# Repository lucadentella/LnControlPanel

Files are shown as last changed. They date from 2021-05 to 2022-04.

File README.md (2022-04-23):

# LnControlPanel
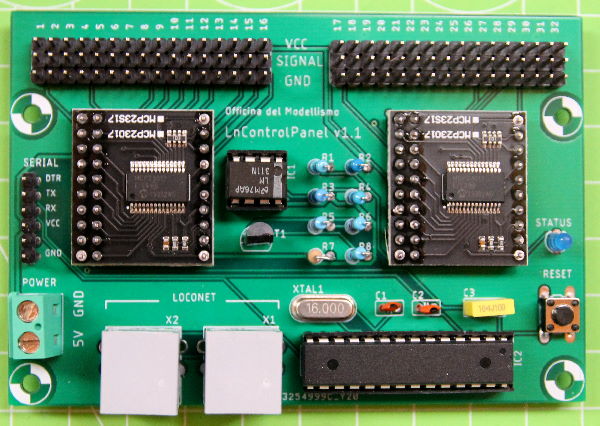
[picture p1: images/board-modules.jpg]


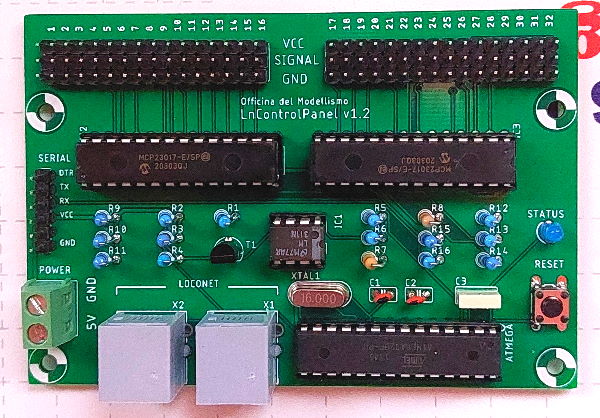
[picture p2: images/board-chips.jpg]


## Description

LnControlPanel is an opensource board to create Loconet control panels.



## What's new :tada:

- 23/04/2022, new board version, with MCP23017 chips instead of CJMCU modules
- 05/03/2022, new firmware (2.0) with support for new Adafruit libraries

## Features :trophy:

 - **32** independent channels:
   - each channel can be configured as **input** (to *control*) or as **output** (to *monitor)*
   - each channel can control/monitor a **turnout** or a **sensor**
   - each channel can have its own **address**
 - Two Loconet connectors for **cascade** connection
 - Based on **Arduino** framework and opensource libraries
 - Configurable using a simple **menu** via **serial** connection

## Tutorials :video_camera:
 - [LnControlPanel on Youtube (ENG)](https://youtu.be/r6l4IHOCdZg)
 - [LnControlPanel su Youtube (ITA)](https://youtu.be/eZ9PHgq4dks)

## Resources :open_file_folder:
 - [Eagle files - board with CJMCU modules](https://github.com/lucadentella/LnControlPanel/tree/main/Eagle/Modules) (schematic / PCB)
 - [Eagle files - board with MCP23017 chips](https://github.com/lucadentella/LnControlPanel/tree/main/Eagle/Chips) (schematic / PCB) 
 - [Arduino firmware](https://github.com/lucadentella/LnControlPanel/tree/main/Arduino)

## Documentation :notebook:
 - [Schematic - board with CJMCU modules](https://github.com/lucadentella/LnControlPanel/tree/main/Documentation/Schematics-modules.pdf) (PDF)
 - [Schematic - board with MCP23017 chips](https://github.com/lucadentella/LnControlPanel/tree/main/Documentation/Schematics-chips.pdf) (PDF)
 - [Part list](https://github.com/lucadentella/LnControlPanel/tree/main/Documentation/PARTLIST.md)
 - [How to configure the channels](https://github.com/lucadentella/LnControlPanel/tree/main/Documentation/CONFIGURATION.md)
 - [How to connect buttons/LEDs](https://github.com/lucadentella/LnControlPanel/tree/main/Documentation/CONNECTIONS.md) 

## Requirements :heavy_check_mark:
 - [mrrwa Loconet Library](https://github.com/mrrwa/LocoNet)
 - [Adafruit MCP23017 Library](https://github.com/adafruit/Adafruit-MCP23017-Arduino-Library)

*The libraries above can be installed via the* [Library Manager](https://www.arduino.cc/en/guide/libraries)

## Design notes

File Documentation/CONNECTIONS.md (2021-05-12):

# Connections :zap:

LnControlPanel has **32 independent** channels. Each channel can be connected to:
 - a **BUTTON** (if the channel is in INPUT mode)
 - one or two **LEDs** (if the channel is in OUTPUT mode)

See [Configuration](https://github.com/lucadentella/LnControlPanel/blob/main/Documentation/CONFIGURATION.md) to learn how to configure channel properties. 
 
 ## INPUT - Button
In INPUT mode, a channel can **control** the status of a sensor or the position of a turnout.

Connect a button between **SIGNAL** and **GND**:

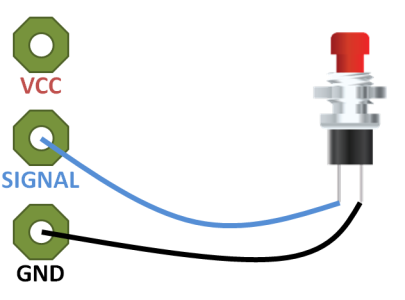
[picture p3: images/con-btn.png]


When the button is pressed, the status of the sensor or the position of the turnout is **switched**.

If the channel is configured as **MSENSOR** (*Momentary Sensor*), the sensor is set **ACTIVE** when the button is pressed and **INACTIVE** when released.

## OUTPUT - LEDs
In OUTPUT mode, a channel can **monitor** the status of a sensor or the position of a turnout.

If you connect the LED between **VCC** and **SIGNAL**, it will be ON if the sensor is **INACTIVE** or the turnout is **STRAIGHT**:
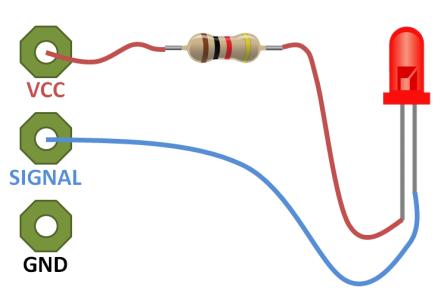
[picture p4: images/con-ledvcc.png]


If you connect the LED between **SIGNAL** and **GND**, it will be ON if the sensor is **ACTIVE** or the turnout is **DIVERGING**:
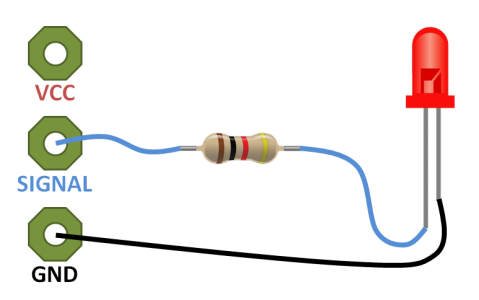
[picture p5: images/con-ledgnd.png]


If you connect **two LEDs** as follows, they will be **ON** based on the turnout position:
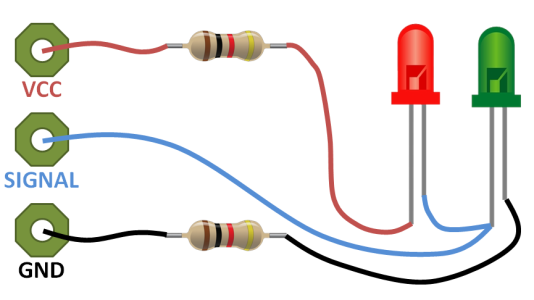
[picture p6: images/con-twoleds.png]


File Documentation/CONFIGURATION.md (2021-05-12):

# Configuration :gear:

LnControlPanel has **32 independent** channels; each channel can be configured in:

 - **OUTPUT** mode (the channel *monitors* an element of the layout)
 - **INPUT** mode (the channel *controls* an element of the layout)

The layout elements associated to each channel can be:
 - **Turnouts**
 - **Sensors**
 - **Momentary** Sensors (*only in* INPUT *mode*)

Each layout element is identified by its **address**.

To summarize, each channel has the following parameters:
|Direction|Device|Address|
|--|--|--|
|Input/Output|Turnout/Sensor/MSensor|*element address*

See [Connections](https://github.com/lucadentella/LnControlPanel/blob/main/Documentation/CONNECTIONS.md) to learn how to connect buttons/LEDs to the channels. 

## Serial console :electric_plug:
It is possible to configure LnControlPanel using a **serial terminal** (for example *Arduino Serial Monitor*).

Using an USB->Serial adapter, connect your computer to the board. 
Make sure that TX and RX pins are **reversed**.

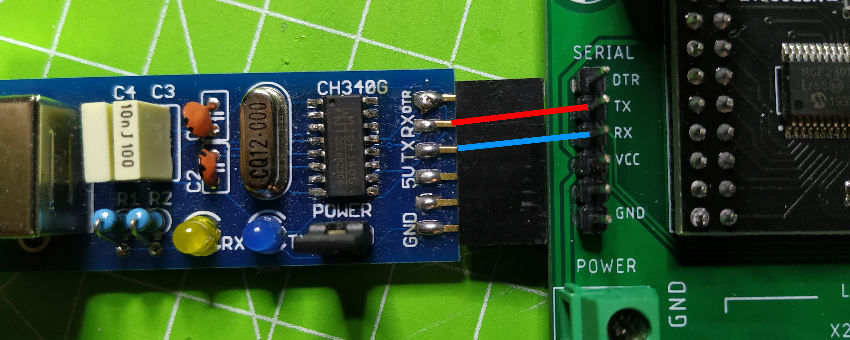
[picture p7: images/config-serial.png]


Open the terminal (**115200** baud, **8N1**, **NL** as line terminator).

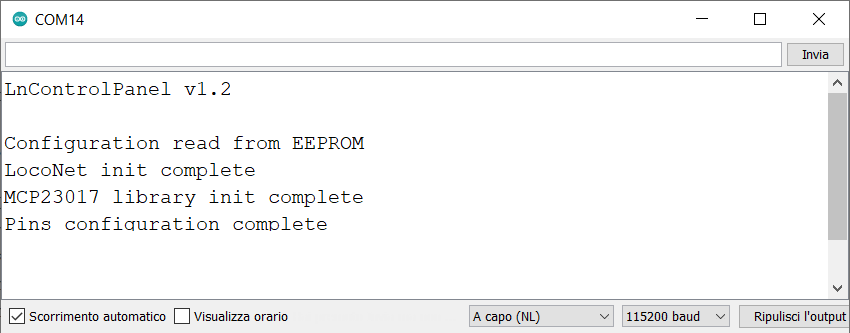
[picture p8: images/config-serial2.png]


The available commands (case sensitive!) are:

 - **INPUT** *ioPin*: set the ioPin as INPUT
 - **OUTPUT** *ioPin*: set the ioPin as OUTPUT
 - **TURNOUT** *ioPin*: set the ioPin as a TURNOUT
 - **SENSOR** *ioPin*: set the ioPin as a SENSOR
 - **MSENSOR** *ioPin*: set the ioPin as a MOMENTARY SENSOR
 - **ADDRESS** *ioPin* *address*: set the address for the ioPin
 - **STATUS**: print the current status
 - **RESET**: reset the configuration to factory
 - **HELP**: print the usage

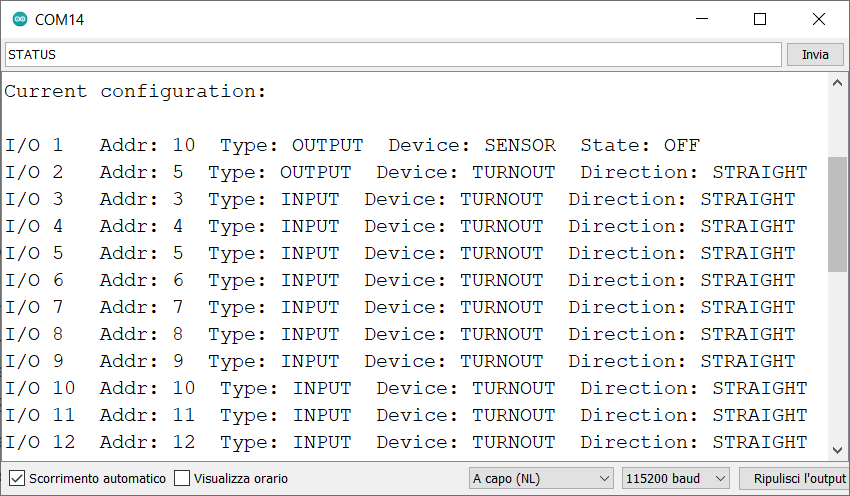
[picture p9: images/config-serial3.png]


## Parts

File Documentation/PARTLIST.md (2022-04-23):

# Part list :gift:

## CJMCU modules version
| ID | Description | 
|--|--|
| R1 | 1Kohm 1/4W resistor |
| R2,3 | 10Kohm 1/4W resistor |
| R4 | 22Kohm 1/4W resistor |
| R5 | 220Kohm 1/4W resistor |
| R6 | 47Kohm 1/4W resistor |
| R7 | 150Kohm 1/4W resistor |
| R8 | 4.7Kohm 1/4W resistor |
| C1,C2 | 22pF ceramic capacitor |
| C3 | 100nF ceramic capacitor |
| XTAL1 | 16MHz crystal oscillator |
| T1 | BC337 NPN transistor |
| LED1 | 3mm LED |
| IC1 | LM311N |
| U1 | ATmega328p |
| M1,M2 | CJMCU-2317 module |
| RESET_SW | Tactile pushbutton |
| X1,X2 | RJ11 PCB connector |
| X3 | 2P terminal block |
| JP1,JP2 | 3x16 pin header |
| JP3 | 1x6 pin header |

## MCP23017 chips version
| ID | Description | 
|--|--|
| R1 | 1Kohm 1/4W resistor |
| R2,3,9,10,11,12,13,14,15,16 | 10Kohm 1/4W resistor |
| R4 | 22Kohm 1/4W resistor |
| R5 | 220Kohm 1/4W resistor |
| R6 | 47Kohm 1/4W resistor |
| R7 | 150Kohm 1/4W resistor |
| R8 | 4.7Kohm 1/4W resistor |
| C1,C2 | 22pF ceramic capacitor |
| C3 | 100nF ceramic capacitor |
| XTAL1 | 16MHz crystal oscillator |
| T1 | BC337 NPN transistor |
| LED1 | 3mm LED |
| IC1 | LM311N |
| U1 | ATmega328p |
| IC2,IC3 | MCP23017 PDIP-28 |
| RESET_SW | Tactile pushbutton |
| X1,X2 | RJ11 PCB connector |
| X3 | 2P terminal block |
| JP1,JP2 | 3x16 pin header |
| JP3 | 1x6 pin header |

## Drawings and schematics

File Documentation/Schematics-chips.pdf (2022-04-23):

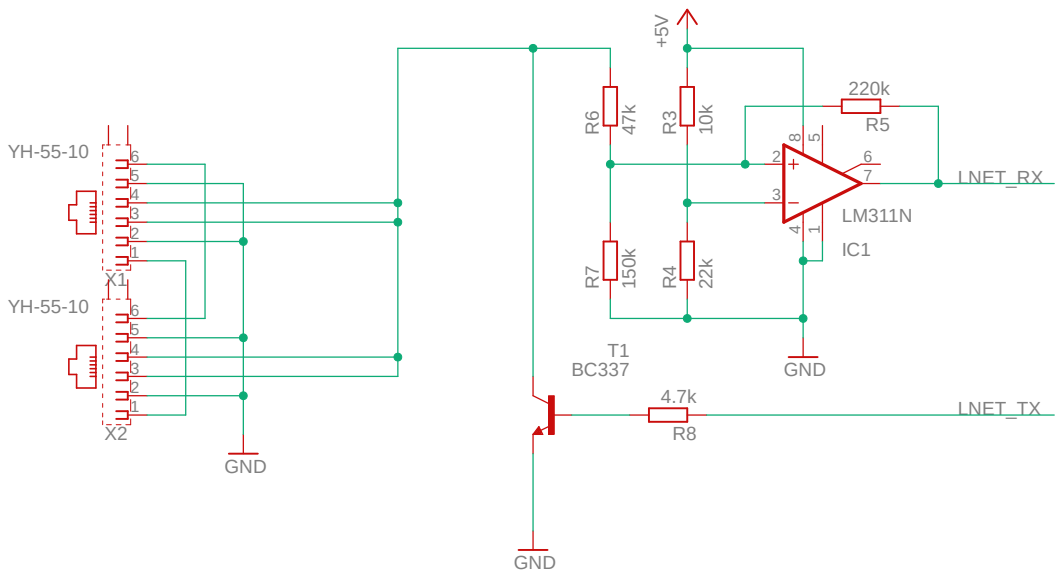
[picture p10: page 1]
LM311N ¹⁰k +5V; GND ²²k; GND; R8 ¹²³⁴⁵⁶ X1 123456 X2; LNET_RX; LNET_TX

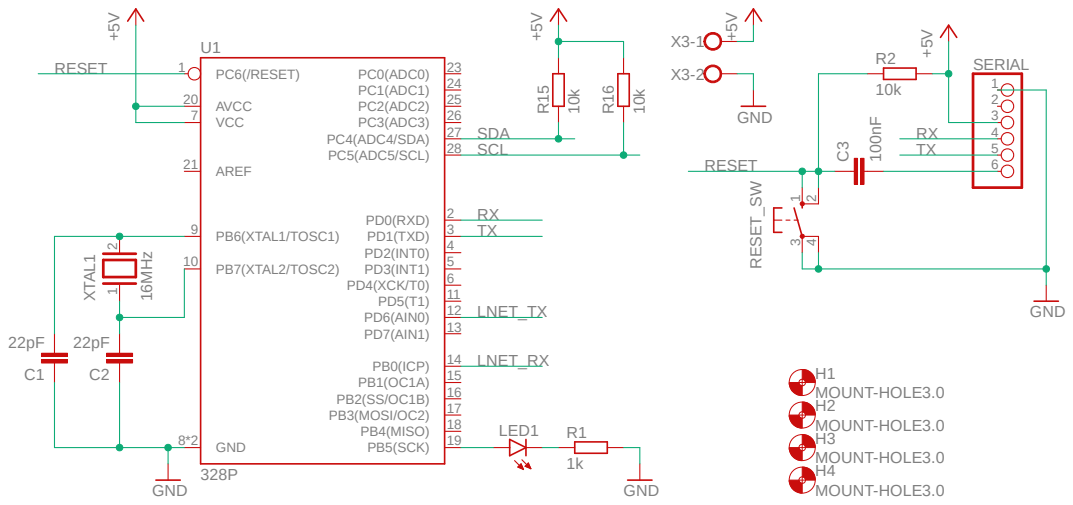
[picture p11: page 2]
GND ⁺⁵V; 16MHz; GND ¹⁰⁰nF; GND; MOUNT-HOLE3.0; MOUNT-HOLE3.0 ⁺⁵V; PB5(SCK); PB7(XTAL2/TOSC2) 10; PB6(XTAL1/TOSC1) 9; GND 8*2; VCC 7; AREF 21; AVCC 20; PB4(MISO); 18 PB3(MOSI/OC2); 15 PB0(ICP); PD7(AIN1); 13 PD6(AIN0); 11 PD4(XCK/T0); PD3(INT1); PD2(INT0); PD1(TXD); PD0(RXD); PC5(ADC5/SCL); 28 PC4(ADC4/SDA); 27 PC3(ADC3); 26 PC2(ADC2); 25 PC1(ADC1); 24 PC0(ADC0); 23 PC6(/RESET) 1 U1; 2 1XTAL1; R2 3 12 4 RESET_SW; 6 SERIAL C³; LED1; X3-2 R¹⁵; R¹⁶; RESET; LNET_TX; LNET_RX; SCL; SDA

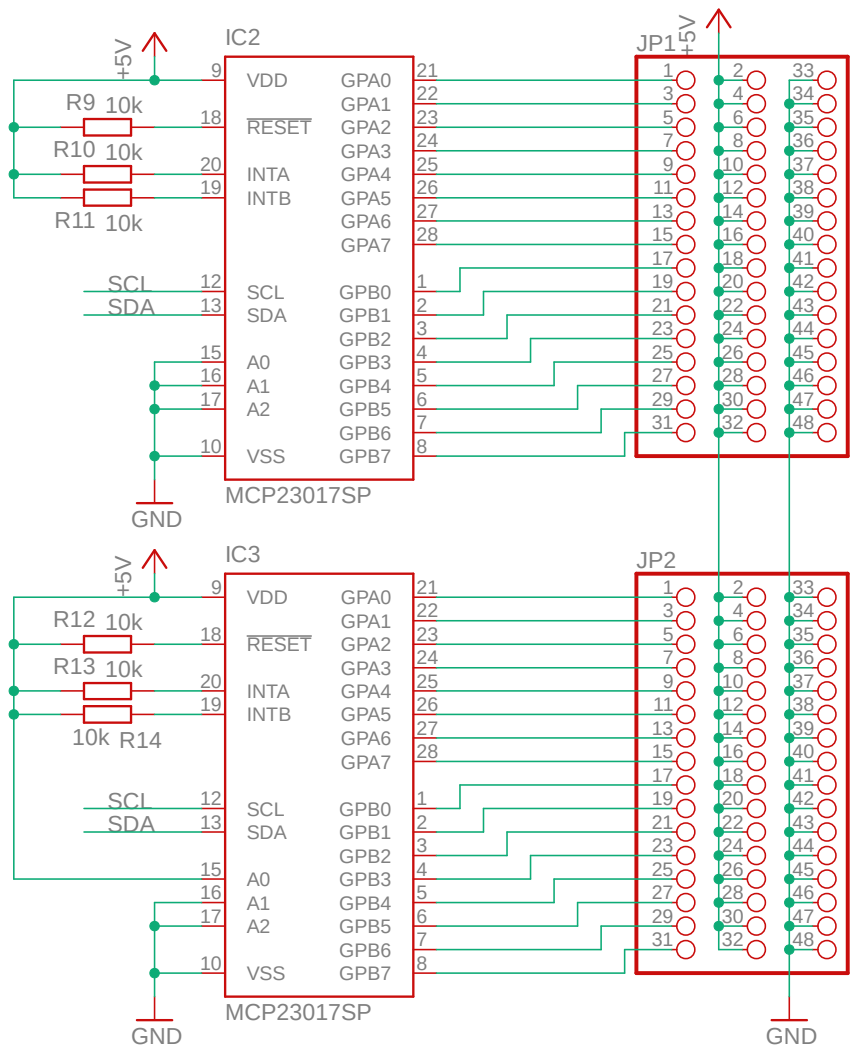
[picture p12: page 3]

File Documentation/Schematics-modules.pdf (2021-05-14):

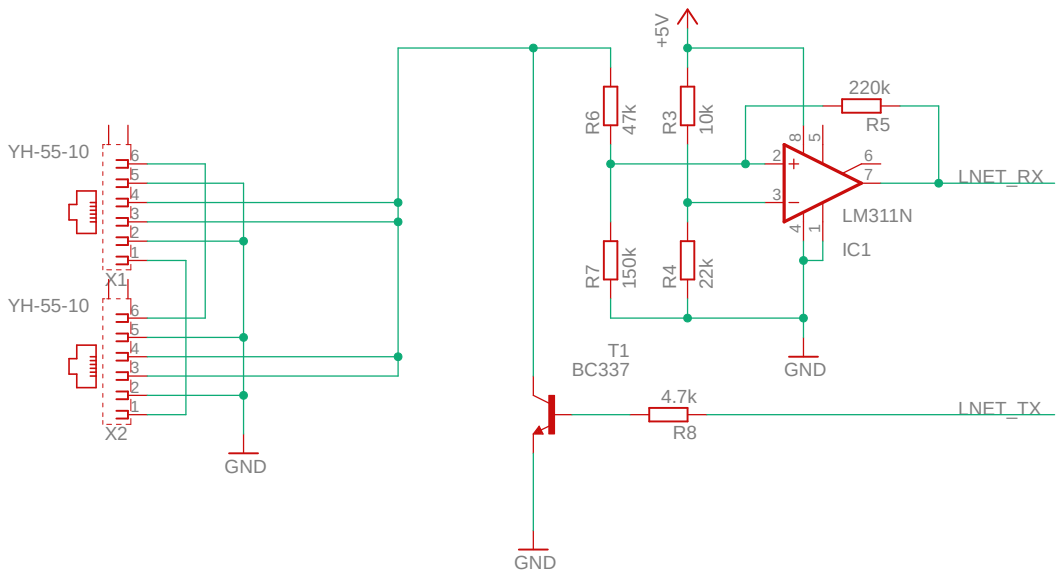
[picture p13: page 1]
LM311N ¹⁰k +5V; GND ²²k; GND; R8 ¹²³⁴⁵⁶ X1 123456 X2; LNET_RX; LNET_TX

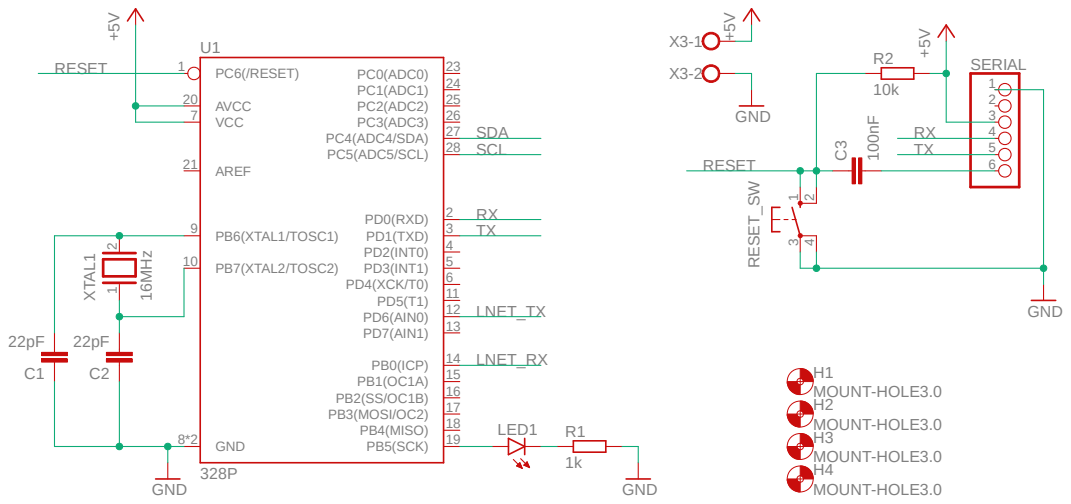
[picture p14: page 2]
GND ⁺⁵V; 16MHz; GND ¹⁰⁰nF; GND; MOUNT-HOLE3.0; MOUNT-HOLE3.0 ⁺⁵V; PB5(SCK); PB7(XTAL2/TOSC2) 10; PB6(XTAL1/TOSC1) 9; GND 8*2; VCC 7; AREF 21; AVCC 20; PB4(MISO); 18 PB3(MOSI/OC2); 15 PB0(ICP); PD7(AIN1); 13 PD6(AIN0); 11 PD4(XCK/T0); PD3(INT1); PD2(INT0); PD1(TXD); PD0(RXD); PC5(ADC5/SCL); 28 PC4(ADC4/SDA); 27 PC3(ADC3); 26 PC2(ADC2); 25 PC1(ADC1); 24 PC0(ADC0); 23 PC6(/RESET) 1 U1; 2 1XTAL1; R2 3 12 4 RESET_SW; 6 SERIAL C³; LED1; RESET; LNET_TX; LNET_RX; SCL; SDA

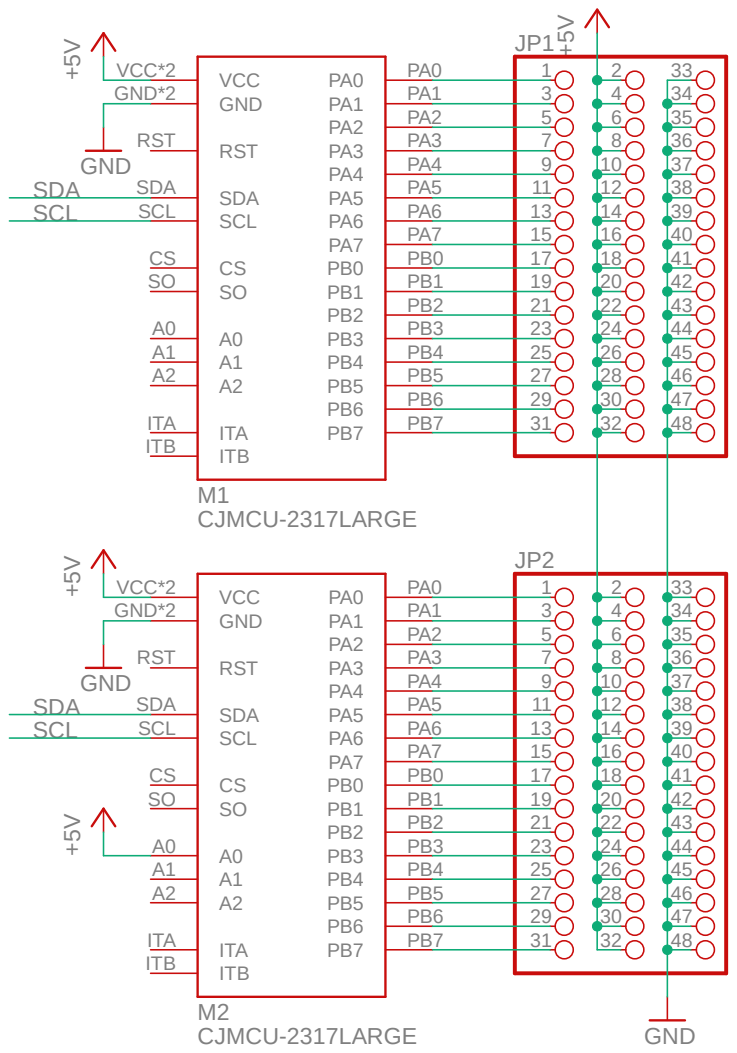
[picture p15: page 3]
CJMCU-2317LARGE; CJMCU-2317LARGE ⁺⁵V +5V; GND; GND +5V; VCC VCC*2 GND GND*2; RST RST; SDA SDA SCL SCL; PB7 ITA ITA; ITB ITB M1; ITB ITB M2; SDA; SCL

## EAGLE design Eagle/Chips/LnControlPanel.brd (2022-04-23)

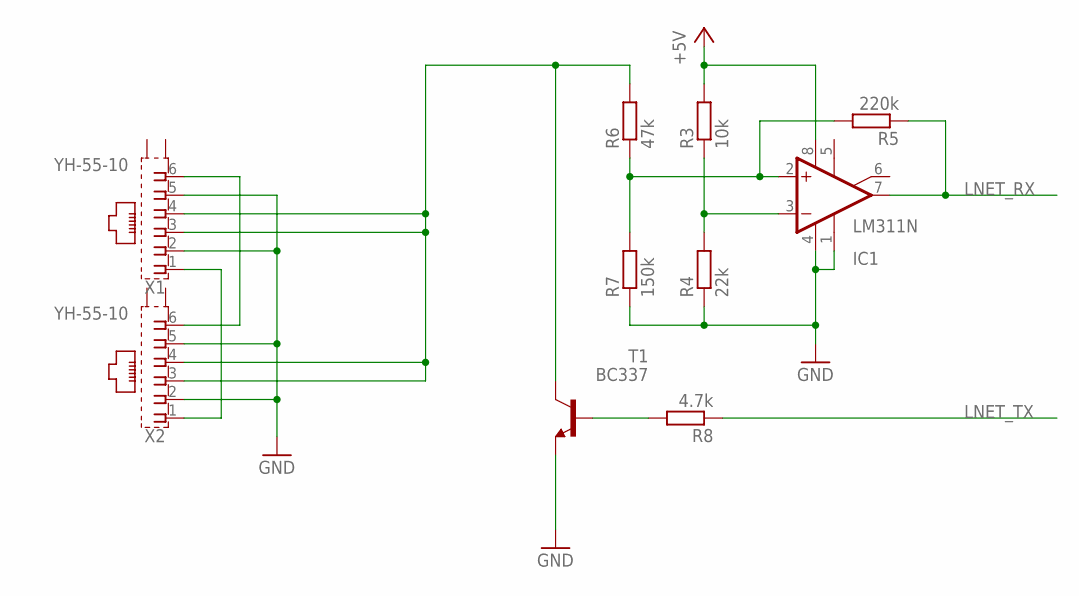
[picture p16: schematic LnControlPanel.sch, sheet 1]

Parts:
IC1: LM311N; DIL08
R3: 10k; 0207/2V
R4: 22k; 0207/2V
R5: 220k; 0207/2V
R6: 47k; 0207/2V
R7: 150k; 0207/2V
R8: 4.7k; 0207/2V
T1: BC337; TO92
X1, X2: YH-55-10

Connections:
+5V: IC1.8 (V+), R3.2; also elsewhere on the board
GND: IC1.1 (GND), IC1.4 (V-), R4.1, R7.1, T1.1 (E), X1.2, X1.5, X2.2, X2.5; also elsewhere on the board
LNET: R6.2, T1.3 (C), X1.3, X1.4, X2.3, X2.4
LNET_RX: IC1.7 (OUT), R5.1; also elsewhere on the board
LNET_TX: R8.1; also elsewhere on the board
unnamed: R8.2, T1.2 (B)
unnamed: IC1.3 (-IN), R3.1, R4.2
unnamed: IC1.2 (+IN), R5.2, R6.1, R7.2
unnamed: X1.1, X2.1
unnamed: X1.6, X2.6

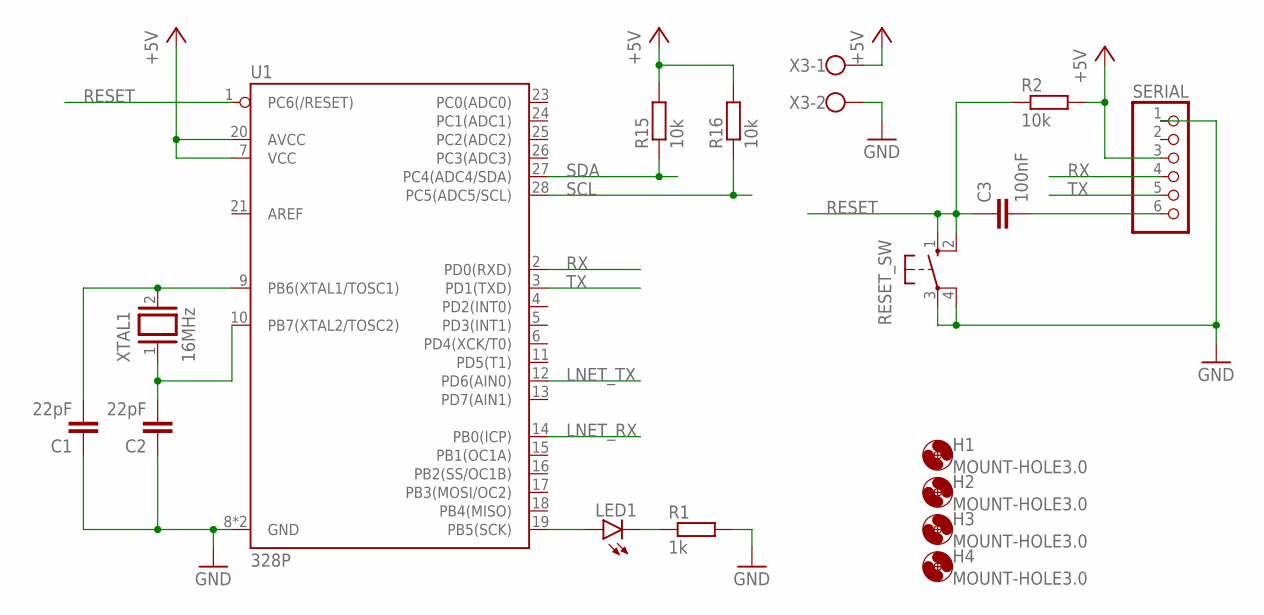
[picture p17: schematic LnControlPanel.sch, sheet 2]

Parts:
C1, C2: 22pF; C025-025X050
C3: 100nF; C050-030X075
H1, H2, H3, H4: MOUNT-HOLE3.0; 3,0
LED1: LED3MM
R1: 1k; 0207/2V
R2, R15, R16: 10k; 0207/2V
RESET_SW: 10-XX; B3F-10XX
SERIAL: PINHD-1X6; 1X06
U1: 328P; DIP28
X3: W237-102
XTAL1: 16MHz; QS

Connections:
+5V: R2.2, R15.2, R16.2, SERIAL.3, U1.7 (VCC), U1.20 (AVCC), X3.1; also elsewhere on the board
GND: C1.1, C2.1, R1.2, RESET_SW.3, RESET_SW.4 (P1), SERIAL.1, U1.8 (GND), U1.22 (GND), X3.2; also elsewhere on the board
LNET_RX: U1.14 (PB0(ICP)); also elsewhere on the board
LNET_TX: U1.12 (PD6(AIN0)); also elsewhere on the board
unnamed: C2.2, U1.10 (PB7(XTAL2/TOSC2)), XTAL1.1
unnamed: C1.2, U1.9 (PB6(XTAL1/TOSC1)), XTAL1.2
unnamed: C3.2, SERIAL.6
unnamed: LED1.A, U1.19 (PB5(SCK))
unnamed: LED1.K (C), R1.1
RESET: C3.1, R2.1, RESET_SW.1 (S), RESET_SW.2 (S1), U1.1 (PC6(/RESET))
RX: SERIAL.4, U1.2 (PD0(RXD))
SCL: R16.1, U1.28 (PC5(ADC5/SCL)); also elsewhere on the board
SDA: R15.1, U1.27 (PC4(ADC4/SDA)); also elsewhere on the board
TX: SERIAL.5, U1.3 (PD1(TXD))

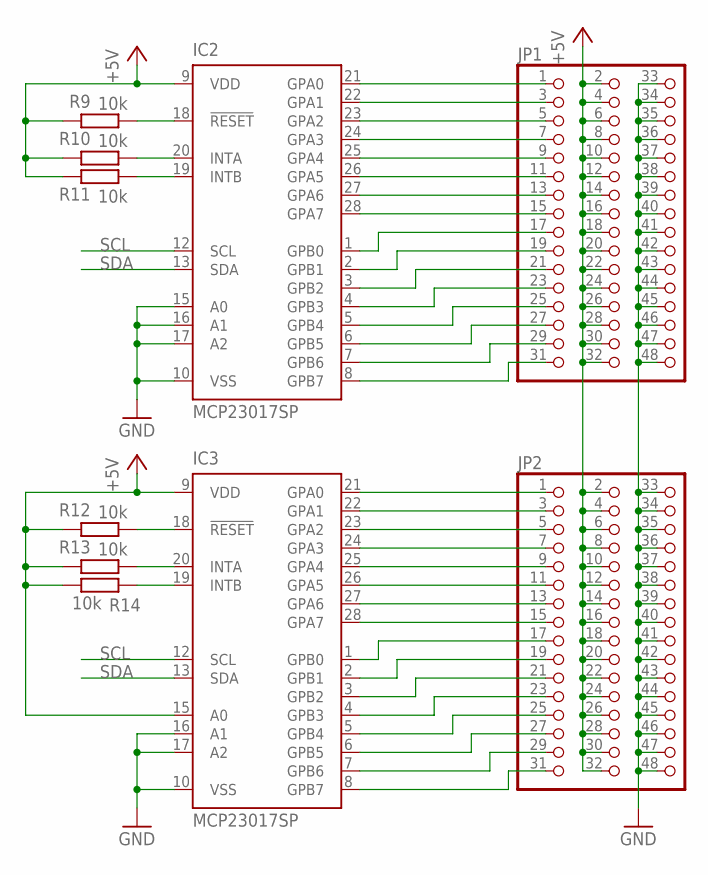
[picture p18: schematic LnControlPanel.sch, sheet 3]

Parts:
IC2, IC3: MCP23017SP; DIL28-3
JP1, JP2: PINHD-3X16; 3X16
R9, R10, R11, R12, R13, R14: 10k; 0207/2V

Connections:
+5V: IC2.9 (VDD), IC3.9 (VDD), IC3.15 (A0), JP1.2, JP1.4, JP1.6, JP1.8, JP1.10, JP1.12, JP1.14, JP1.16, JP1.18, JP1.20, JP1.22, JP1.24, JP1.26, JP1.28, JP1.30, JP1.32, JP2.2, JP2.4, JP2.6, JP2.8, JP2.10, JP2.12, JP2.14, JP2.16, JP2.18, JP2.20, JP2.22, JP2.24, JP2.26, JP2.28, JP2.30, JP2.32, R9.2, R10.2, R11.2, R12.2, R13.2, R14.1; also elsewhere on the board
GND: IC2.10 (VSS), IC2.15 (A0), IC2.16 (A1), IC2.17 (A2), IC3.10 (VSS), IC3.16 (A1), IC3.17 (A2), JP1.33, JP1.34, JP1.35, JP1.36, JP1.37, JP1.38, JP1.39, JP1.40, JP1.41, JP1.42, JP1.43, JP1.44, JP1.45, JP1.46, JP1.47, JP1.48, JP2.33, JP2.34, JP2.35, JP2.36, JP2.37, JP2.38, JP2.39, JP2.40, JP2.41, JP2.42, JP2.43, JP2.44, JP2.45, JP2.46, JP2.47, JP2.48; also elsewhere on the board
unnamed: IC2.21 (GPA0), JP1.1
unnamed: IC2.22 (GPA1), JP1.3
unnamed: IC2.23 (GPA2), JP1.5
unnamed: IC2.24 (GPA3), JP1.7
unnamed: IC2.25 (GPA4), JP1.9
unnamed: IC2.26 (GPA5), JP1.11
unnamed: IC2.27 (GPA6), JP1.13
unnamed: IC2.28 (GPA7), JP1.15
unnamed: IC2.1 (GPB0), JP1.17
unnamed: IC2.2 (GPB1), JP1.19
unnamed: IC2.3 (GPB2), JP1.21
unnamed: IC2.4 (GPB3), JP1.23
unnamed: IC2.5 (GPB4), JP1.25
unnamed: IC2.6 (GPB5), JP1.27
unnamed: IC2.7 (GPB6), JP1.29
unnamed: IC2.8 (GPB7), JP1.31
unnamed: IC3.21 (GPA0), JP2.1
unnamed: IC3.22 (GPA1), JP2.3
unnamed: IC3.23 (GPA2), JP2.5
unnamed: IC3.24 (GPA3), JP2.7
unnamed: IC3.25 (GPA4), JP2.9
unnamed: IC3.26 (GPA5), JP2.11
unnamed: IC3.27 (GPA6), JP2.13
unnamed: IC3.28 (GPA7), JP2.15
unnamed: IC3.1 (GPB0), JP2.17
unnamed: IC3.2 (GPB1), JP2.19
unnamed: IC3.3 (GPB2), JP2.21
unnamed: IC3.4 (GPB3), JP2.23
unnamed: IC3.5 (GPB4), JP2.25
unnamed: IC3.6 (GPB5), JP2.27
unnamed: IC3.7 (GPB6), JP2.29
unnamed: IC3.8 (GPB7), JP2.31
unnamed: IC3.18 (!RESET), R12.1
unnamed: IC2.18 (!RESET), R9.1
unnamed: IC2.20 (INTA), R10.1
unnamed: IC2.19 (INTB), R11.1
unnamed: IC3.20 (INTA), R13.1
unnamed: IC3.19 (INTB), R14.2
SCL: IC2.12 (SCL), IC3.12 (SCL); also elsewhere on the board
SDA: IC2.13 (SDA), IC3.13 (SDA); also elsewhere on the board

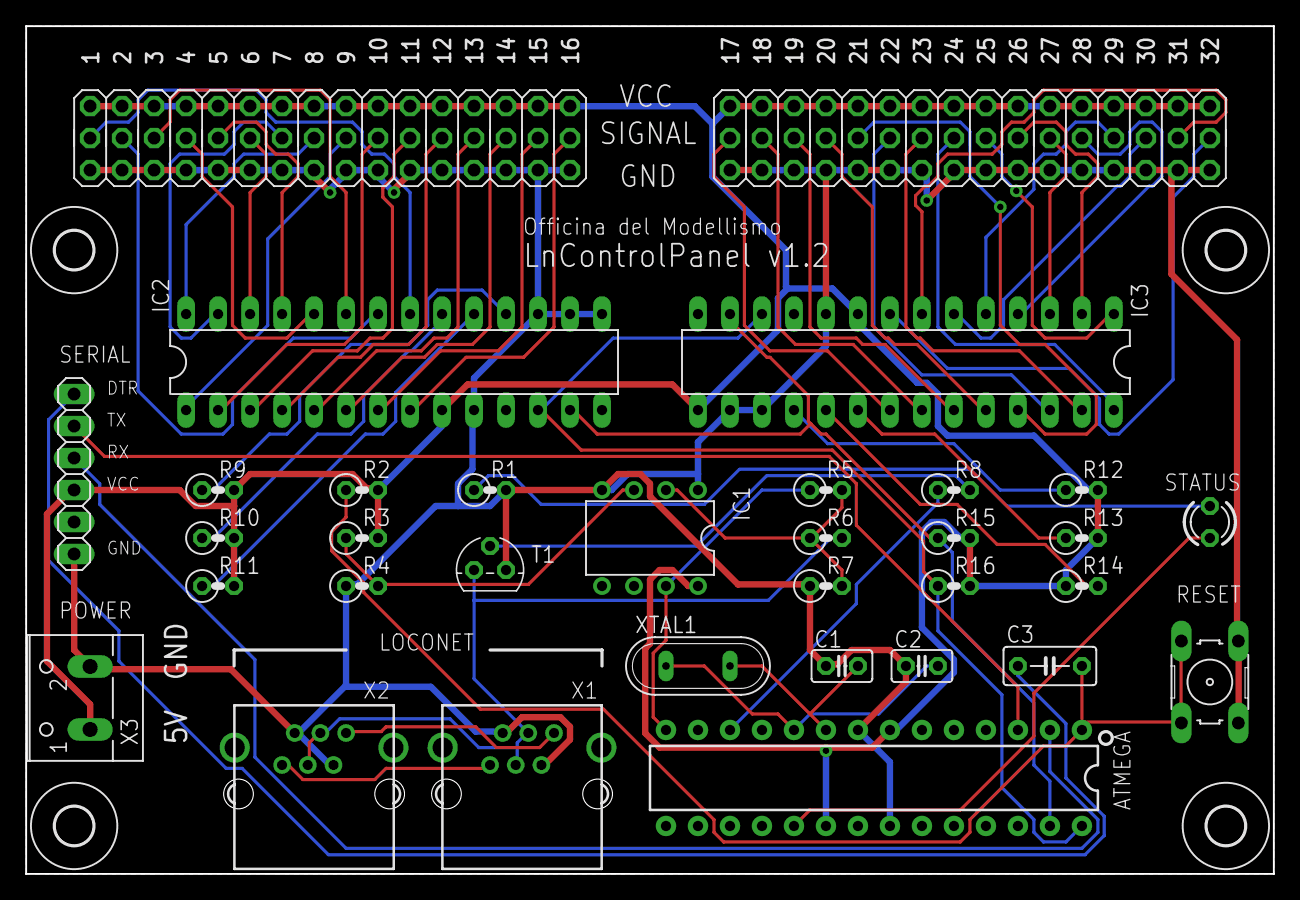
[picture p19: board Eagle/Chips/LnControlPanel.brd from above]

Board: 2 copper layers, 99.1 x 67.3 mm, 37 parts (0 on the bottom side), 58 nets.

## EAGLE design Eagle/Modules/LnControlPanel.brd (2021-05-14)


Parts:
IC1: LM311N; DIL08
R3: 10k; 0207/2V
R4: 22k; 0207/2V
R5: 220k; 0207/2V
R6: 47k; 0207/2V
R7: 150k; 0207/2V
R8: 4.7k; 0207/2V
T1: BC337; TO92
X1, X2: YH-55-10

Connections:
+5V: IC1.8 (V+), R3.2; also elsewhere on the board
GND: IC1.1 (GND), IC1.4 (V-), R4.1, R7.1, T1.1 (E), X1.2, X1.5, X2.2, X2.5; also elsewhere on the board
LNET: R6.2, T1.3 (C), X1.3, X1.4, X2.3, X2.4
LNET_RX: IC1.7 (OUT), R5.1; also elsewhere on the board
LNET_TX: R8.1; also elsewhere on the board
unnamed: R8.2, T1.2 (B)
unnamed: IC1.3 (-IN), R3.1, R4.2
unnamed: IC1.2 (+IN), R5.2, R6.1, R7.2
unnamed: X1.1, X2.1
unnamed: X1.6, X2.6

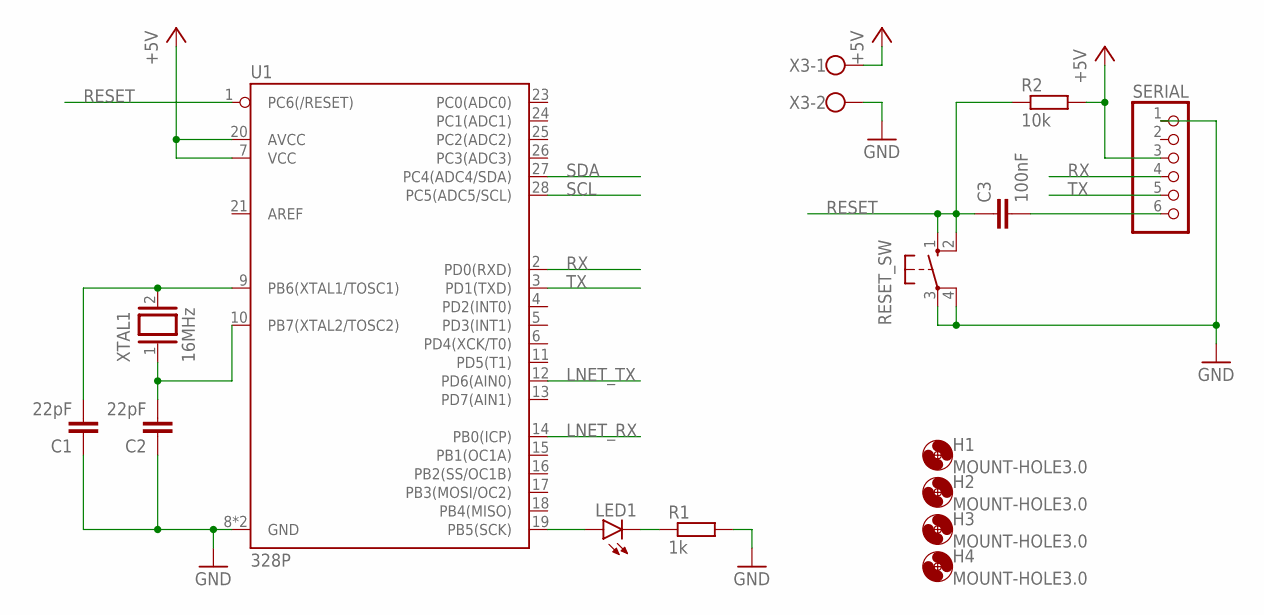
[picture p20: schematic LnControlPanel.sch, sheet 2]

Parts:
C1, C2: 22pF; C025-025X050
C3: 100nF; C050-030X075
H1, H2, H3, H4: MOUNT-HOLE3.0; 3,0
LED1: LED3MM
R1: 1k; 0207/2V
R2: 10k; 0207/2V
RESET_SW: 10-XX; B3F-10XX
SERIAL: PINHD-1X6; 1X06
U1: 328P; DIP28
X3: W237-102
XTAL1: 16MHz; QS

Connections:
+5V: R2.2, SERIAL.3, U1.7 (VCC), U1.20 (AVCC), X3.1; also elsewhere on the board
GND: C1.1, C2.1, R1.2, RESET_SW.3, RESET_SW.4 (P1), SERIAL.1, U1.8 (GND), U1.22 (GND), X3.2; also elsewhere on the board
LNET_RX: U1.14 (PB0(ICP)); also elsewhere on the board
LNET_TX: U1.12 (PD6(AIN0)); also elsewhere on the board
unnamed: C2.2, U1.10 (PB7(XTAL2/TOSC2)), XTAL1.1
unnamed: C1.2, U1.9 (PB6(XTAL1/TOSC1)), XTAL1.2
unnamed: C3.2, SERIAL.6
unnamed: LED1.A, U1.19 (PB5(SCK))
unnamed: LED1.K (C), R1.1
RESET: C3.1, R2.1, RESET_SW.1 (S), RESET_SW.2 (S1), U1.1 (PC6(/RESET))
RX: SERIAL.4, U1.2 (PD0(RXD))
SCL: U1.28 (PC5(ADC5/SCL)); also elsewhere on the board
SDA: U1.27 (PC4(ADC4/SDA)); also elsewhere on the board
TX: SERIAL.5, U1.3 (PD1(TXD))

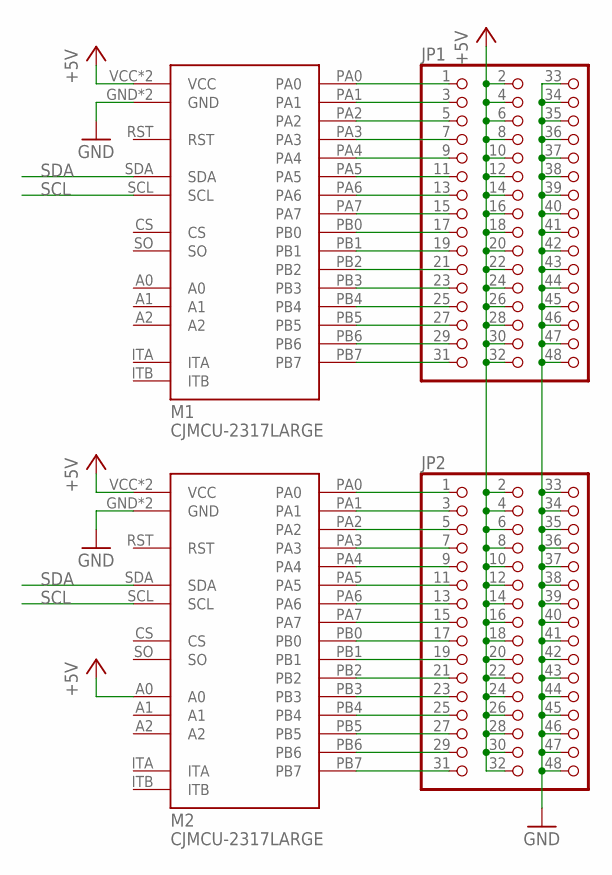
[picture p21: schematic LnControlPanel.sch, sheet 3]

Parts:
JP1, JP2: PINHD-3X16; 3X16
M1, M2: CJMCU-2317LARGE; CJMCU-2317-PACKAGE2

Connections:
+5V: JP1.2, JP1.4, JP1.6, JP1.8, JP1.10, JP1.12, JP1.14, JP1.16, JP1.18, JP1.20, JP1.22, JP1.24, JP1.26, JP1.28, JP1.30, JP1.32, JP2.2, JP2.4, JP2.6, JP2.8, JP2.10, JP2.12, JP2.14, JP2.16, JP2.18, JP2.20, JP2.22, JP2.24, JP2.26, JP2.28, JP2.30, JP2.32, M1.VCC, M1.VCC_2 (VCC), M2.A0, M2.VCC, M2.VCC_2 (VCC); also elsewhere on the board
GND: JP1.33, JP1.34, JP1.35, JP1.36, JP1.37, JP1.38, JP1.39, JP1.40, JP1.41, JP1.42, JP1.43, JP1.44, JP1.45, JP1.46, JP1.47, JP1.48, JP2.33, JP2.34, JP2.35, JP2.36, JP2.37, JP2.38, JP2.39, JP2.40, JP2.41, JP2.42, JP2.43, JP2.44, JP2.45, JP2.46, JP2.47, JP2.48, M1.GND, M1.GND_2 (GND), M2.GND, M2.GND_2 (GND); also elsewhere on the board
unnamed: JP1.1, M1.PA0
unnamed: JP1.3, M1.PA1
unnamed: JP1.5, M1.PA2
unnamed: JP1.7, M1.PA3
unnamed: JP1.9, M1.PA4
unnamed: JP1.11, M1.PA5
unnamed: JP1.13, M1.PA6
unnamed: JP1.15, M1.PA7
unnamed: JP1.17, M1.PB0
unnamed: JP1.19, M1.PB1
unnamed: JP1.21, M1.PB2
unnamed: JP1.23, M1.PB3
unnamed: JP1.25, M1.PB4
unnamed: JP1.27, M1.PB5
unnamed: JP1.29, M1.PB6
unnamed: JP1.31, M1.PB7
unnamed: JP2.1, M2.PA0
unnamed: JP2.3, M2.PA1
unnamed: JP2.5, M2.PA2
unnamed: JP2.7, M2.PA3
unnamed: JP2.9, M2.PA4
unnamed: JP2.11, M2.PA5
unnamed: JP2.13, M2.PA6
unnamed: JP2.15, M2.PA7
unnamed: JP2.17, M2.PB0
unnamed: JP2.19, M2.PB1
unnamed: JP2.21, M2.PB2
unnamed: JP2.23, M2.PB3
unnamed: JP2.25, M2.PB4
unnamed: JP2.27, M2.PB5
unnamed: JP2.29, M2.PB6
unnamed: JP2.31, M2.PB7
SCL: M1.SCL, M2.SCL; also elsewhere on the board
SDA: M1.SDA, M2.SDA; also elsewhere on the board

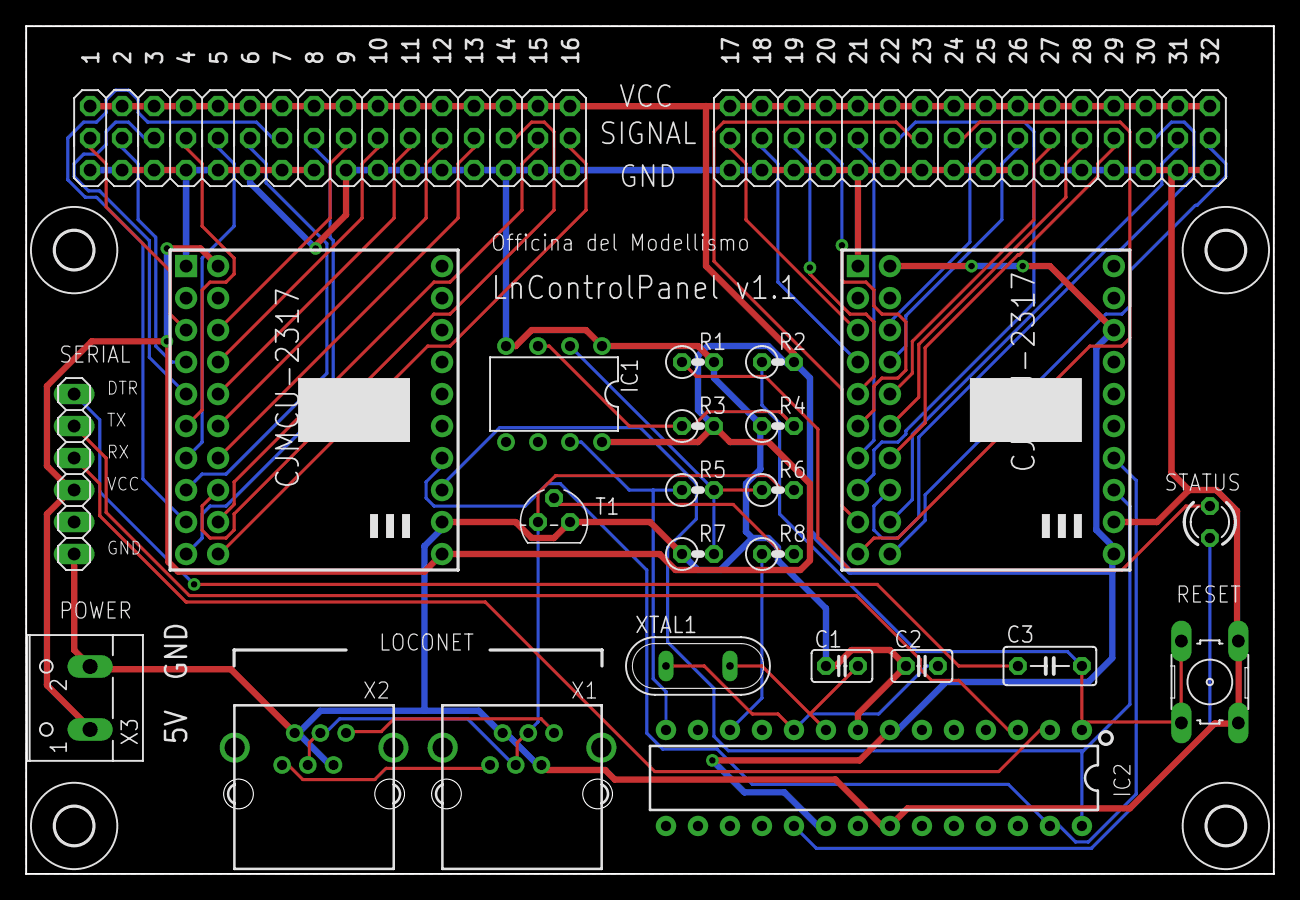
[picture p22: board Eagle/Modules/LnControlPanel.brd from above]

Board: 2 copper layers, 99.1 x 67.3 mm, 29 parts (0 on the bottom side), 52 nets.

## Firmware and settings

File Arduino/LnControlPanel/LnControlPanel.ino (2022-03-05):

#include <LocoNet.h>
#include <Wire.h>
#include <EEPROM.h>
#include <Adafruit_MCP23X17.h>

// LnControlPanel 2.0

// Support for the updated version of Adafruit Library (tested with v2.1)
// https://github.com/adafruit/Adafruit-MCP23017-Arduino-Library

// Make sure you have an updated version of Adafruit BusIO too
// https://github.com/adafruit/Adafruit_BusIO

// Definitions
#define VERSION       "2.0"
#define IOPINS        32
#define CONFIGVALID   111
#define CMDLINESIZE   100
#define DEV_TURNOUT   0
#define DEV_SENSOR    1
#define DEV_MSENSOR   2
#define SWITCH_MS     200  

// Pins configuration
typedef struct {
  int dccAddress;
  bool isInput;
  int deviceType;
} PinInfo;

// Global variables
Adafruit_MCP23X17 mcp1;
Adafruit_MCP23X17 mcp2;
lnMsg *LnPacket;
PinInfo pinInfo[IOPINS];
bool isPinStraight[IOPINS];
bool wasPinDown[IOPINS];
char cmdline[CMDLINESIZE];
int cmdlinepos = 0;

void setup() {
  
  Serial.begin(115200);
  Serial.print("LnControlPanel v");
  Serial.println(VERSION);
  Serial.println();

  // check if the configuration in the EEPROM is valid
  if(EEPROM.read(EEPROM.length() - 1) == CONFIGVALID) readConfigFromEEPROM();
  else {
    Serial.println(F("Configuration in EEPROM is invalid"));
    resetConfiguration();
    saveConfigToEEPROM();
    EEPROM.update(EEPROM.length() - 1, CONFIGVALID);
  }

  // start with direction = straight for all the pins and all the buttons UP
  for(int i = 0; i < IOPINS; i++) {
    isPinStraight[i] = true;
    wasPinDown[i] = false;
  }

  LocoNet.init();
  Serial.println(F("LocoNet init complete"));

  mcp1.begin_I2C(0x20);
  mcp2.begin_I2C(0x21);
  Serial.println(F("MCP23017 library init complete"));
 
  for(int i = 0; i < IOPINS; i++) setPinDirection(i, pinInfo[i].isInput);
  for(int i = 0; i < IOPINS; i++) if(!pinInfo[i].isInput) writePinOutput(i, LOW);
  Serial.println(F("Pins configuration complete"));
  Serial.println();
}

void loop() {

  LnPacket = LocoNet.receive();
  if(LnPacket) LocoNet.processSwitchSensorMessage(LnPacket);

  checkInputs();

  if (Serial.available() > 0) {
    
    int inByte = Serial.read();
    Serial.write(inByte);

    if(inByte == '\n') {
      cmdline[cmdlinepos] = '\0';
      parseCmdLine();
    }
    else {   
      cmdline[cmdlinepos] = inByte;
      cmdlinepos++;
      if(cmdlinepos == CMDLINESIZE) cmdlinepos = 0;
    }
  }
}

void notifySwitchRequest(uint16_t Address, uint8_t Output, uint8_t Direction) {

  Serial.print("Received switch command - ");
  Serial.print("address: "); Serial.print(Address);
  Serial.print(", direction: "); if(Direction > 0) Serial.println("DIVERGING"); else Serial.println("STRAIGHT");

  for(int i = 0; i < IOPINS; i++) {
    if(pinInfo[i].dccAddress == Address && pinInfo[i].deviceType == DEV_TURNOUT) {
      isPinStraight[i] = (Direction == 0);
      if(!pinInfo[i].isInput) writePinOutput(i, Direction);
    }
  }
}

void notifySensor(uint16_t Address, uint8_t State) {

  Serial.print("Received sensor state - ");
  Serial.print("address: "); Serial.print(Address);
  Serial.print(", state: "); if(State > 0) Serial.println("ON"); else Serial.println("OFF");

  for(int i = 0; i < IOPINS; i++) {
    if(pinInfo[i].dccAddress == Address && (pinInfo[i].deviceType == DEV_SENSOR || pinInfo[i].deviceType == DEV_MSENSOR)) {
      isPinStraight[i] = (State == 0);
      if(!pinInfo[i].isInput) writePinOutput(i, State);
    }
  }
}

// set pin direction
void setPinDirection(uint8_t p, bool isInput) {

  if(!isInput) {
    if(p < 16) mcp1.pinMode(p, OUTPUT);
    else mcp2.pinMode(p - 16, OUTPUT);
  } else {
    if(p < 16) mcp1.pinMode(p, INPUT_PULLUP);
    else mcp2.pinMode(p - 16, INPUT_PULLUP);
  }
}

// write output
void writePinOutput(uint8_t p, uint8_t d) {

  if(p < 16) mcp1.digitalWrite(p, d);
  else mcp2.digitalWrite(p - 16, d);
}

// check inputs
void checkInputs() {

  for(int i = 0; i < IOPINS; i++) {

    if(pinInfo[i].isInput) {

      uint8_t buttonStatus;
      if(i < 16) buttonStatus = mcp1.digitalRead(i);
      else buttonStatus = mcp2.digitalRead(i - 16);

      // button pressed
      if(buttonStatus == 0 && !wasPinDown[i]) {
        wasPinDown[i] = true;
        if(pinInfo[i].deviceType == DEV_TURNOUT) {
          LocoNet.requestSwitch(pinInfo[i].dccAddress, 1, isPinStraight[i]);
          delay(SWITCH_MS);
          LocoNet.requestSwitch(pinInfo[i].dccAddress, 0, isPinStraight[i]);
          Serial.print("Sent switch command - ");
          Serial.print("address: "); Serial.print(pinInfo[i].dccAddress);
          Serial.print(", direction: "); if(isPinStraight[i] > 0) Serial.println("DIVERGING"); else Serial.println("STRAIGHT"); 
        } else {
          LocoNet.reportSensor(pinInfo[i].dccAddress, isPinStraight[i]);
          Serial.print("Sent sensor state - ");
          Serial.print("address: "); Serial.print(pinInfo[i].dccAddress);
          Serial.print(", state: "); Serial.println("ON");           
        }       
      } else if (buttonStatus != 0) {
        
        if(wasPinDown[i] && pinInfo[i].deviceType == DEV_MSENSOR) {
          LocoNet.reportSensor(pinInfo[i].dccAddress, 0);
          Serial.print("Sent sensor state - ");
          Serial.print("address: "); Serial.print(pinInfo[i].dccAddress);
          Serial.print(", state: "); Serial.println("OFF");            
        }
        wasPinDown[i] = false;
      }
    }
  }
}

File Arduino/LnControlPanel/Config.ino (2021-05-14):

// restore the configuration from EEPROM
void readConfigFromEEPROM() {

  int currentAddress = 0;
  for(int i = 0; i < IOPINS; i++) {

    EEPROM.get(currentAddress, pinInfo[i]);
    currentAddress += sizeof(PinInfo);
  }

  Serial.println(F("Configuration read from EEPROM"));
}

// save the configuration to EEPROM
void saveConfigToEEPROM() {

  int currentAddress = 0;
  for(int i = 0; i < IOPINS; i++) {

    EEPROM.put(currentAddress, pinInfo[i]);
    currentAddress += sizeof(PinInfo);
  }

  Serial.println(F("Configuration saved to EEPROM"));
}

// reset the configuration to default values
void resetConfiguration() {

  for(int i = 0; i < IOPINS / 2; i++) {
    
    pinInfo[i].dccAddress = i + 1;
    pinInfo[IOPINS / 2 + i].dccAddress = i + 1;
    pinInfo[i].isInput = true;
    pinInfo[IOPINS / 2 + i].isInput = false;
    pinInfo[i].deviceType = DEV_TURNOUT;
    pinInfo[IOPINS / 2 + i].deviceType = DEV_TURNOUT;
  }
  Serial.println(F("Configuration reset to default values"));  
}

// print the current configuration
void printConfiguration() {

  Serial.println("Current configuration:");
  Serial.println();

  for(int i = 0; i < IOPINS; i++) {

    Serial.print("I/O "); Serial.print(i + 1); Serial.print("\t");
    Serial.print("Addr: "); Serial.print(pinInfo[i].dccAddress); Serial.print("  ");
    Serial.print("Type: "); pinInfo[i].isInput ? Serial.print("INPUT") : Serial.print("OUTPUT"); Serial.print("  ");
    Serial.print("Device: "); 
    if(pinInfo[i].deviceType == DEV_TURNOUT) Serial.print("TURNOUT");
    else if(pinInfo[i].deviceType == DEV_SENSOR) Serial.print("SENSOR"); 
    else Serial.print("MSENSOR");
    Serial.print("  ");
    if(pinInfo[i].deviceType == DEV_TURNOUT) { Serial.print("Direction: "); isPinStraight[i] ? Serial.print("STRAIGHT") : Serial.print("DIVERGING"); Serial.print("\n"); } 
    else { Serial.print("State: "); isPinStraight[i] ? Serial.print("OFF") : Serial.print("ON"); Serial.print("\n"); }
  }
}

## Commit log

2021-05-14 Arduino and Eagle files added
    [LnControlPanel.brd, LnControlPanel.sch]
2021-05-14 Schematic in PDF added
2021-09-03 Updated Loconet switch command for more compatibility
2022-03-05 Adafruit MCP library updated and bugfixing
    [LnControlPanel.ino]
2022-04-23 New board version added, with MCP23017 chips instead of CJMCU modules
    [LnControlPanel.brd, LnControlPanel.sch]

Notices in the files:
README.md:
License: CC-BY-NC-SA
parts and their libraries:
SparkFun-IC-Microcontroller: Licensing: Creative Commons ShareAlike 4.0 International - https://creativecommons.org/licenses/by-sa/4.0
